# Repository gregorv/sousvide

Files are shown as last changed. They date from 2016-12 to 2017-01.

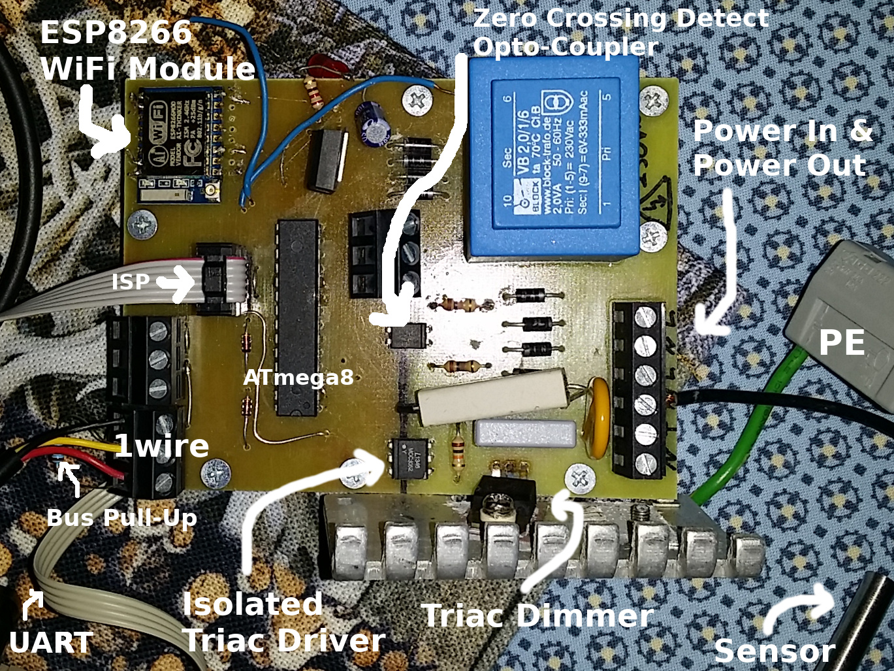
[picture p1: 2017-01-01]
sousvide_ugly_af.jpg

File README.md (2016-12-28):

# sousvide
An ATmega8 based Sous-Vide Temperature Controller

Sous-Vide is a cooking method for a very gentle preparation of meat and vegetables. The general idea is sealing the
food in a vacuum bed and then cooking it in a water bath with a maximum temperature of about 60°C to 70°C for an extended time.
Important cooking reactions (including sterilization) start at around 50°C, but unwanted processes (e.g. meat getting stringy)
increase above 70°C. Because of the lower temperatures the cooking time is elonged, but you get a very even and reproducible
result from the process.

## Overview
### Hardware
On the hardware side (schematics and layout KiCAD format) an ATmega8 regulates the temperature of the water bath with a TRIAC
controlled immersion heater. It is advised to use an acquarium water pump to better spread the heat in the bath. A DS18x2x type
Dallas 1Wire sensor is used for temperature monitoring. The UART can be used to communicate with a ESP8266 type WiFi module, but
is used in the prototype for serial communication and control.

### Firmware
A straight-forward, modularized fixed-point PID controller.

Uses the UART library from Peter Fleury, the 1wire library by Peter Dannegger and the libfixmath by Ben Brewer.

### PC Control Software
Qt5, QCustomPlot, nice.

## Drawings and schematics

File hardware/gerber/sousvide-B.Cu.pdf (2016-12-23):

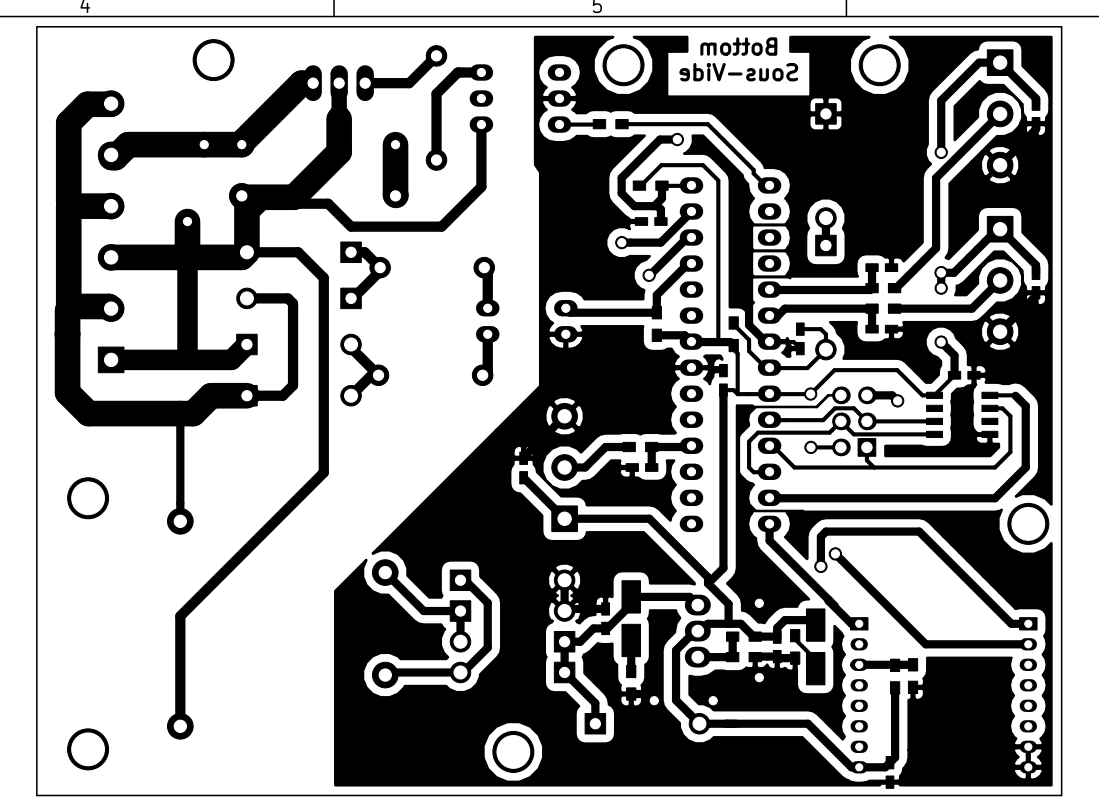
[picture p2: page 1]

Gregor Vollmer
File: sousvide.kicad_pcb Sheet: dynamic-noise.net

Id: 1/1 Title: Sous-Vide Temperature Controler

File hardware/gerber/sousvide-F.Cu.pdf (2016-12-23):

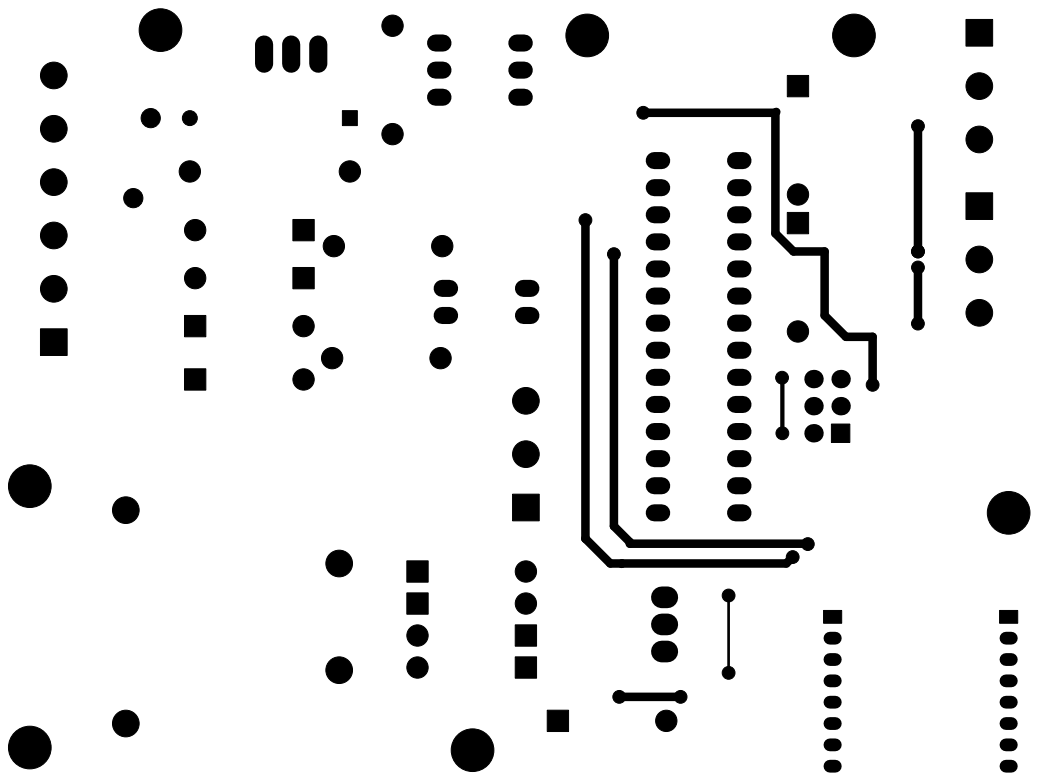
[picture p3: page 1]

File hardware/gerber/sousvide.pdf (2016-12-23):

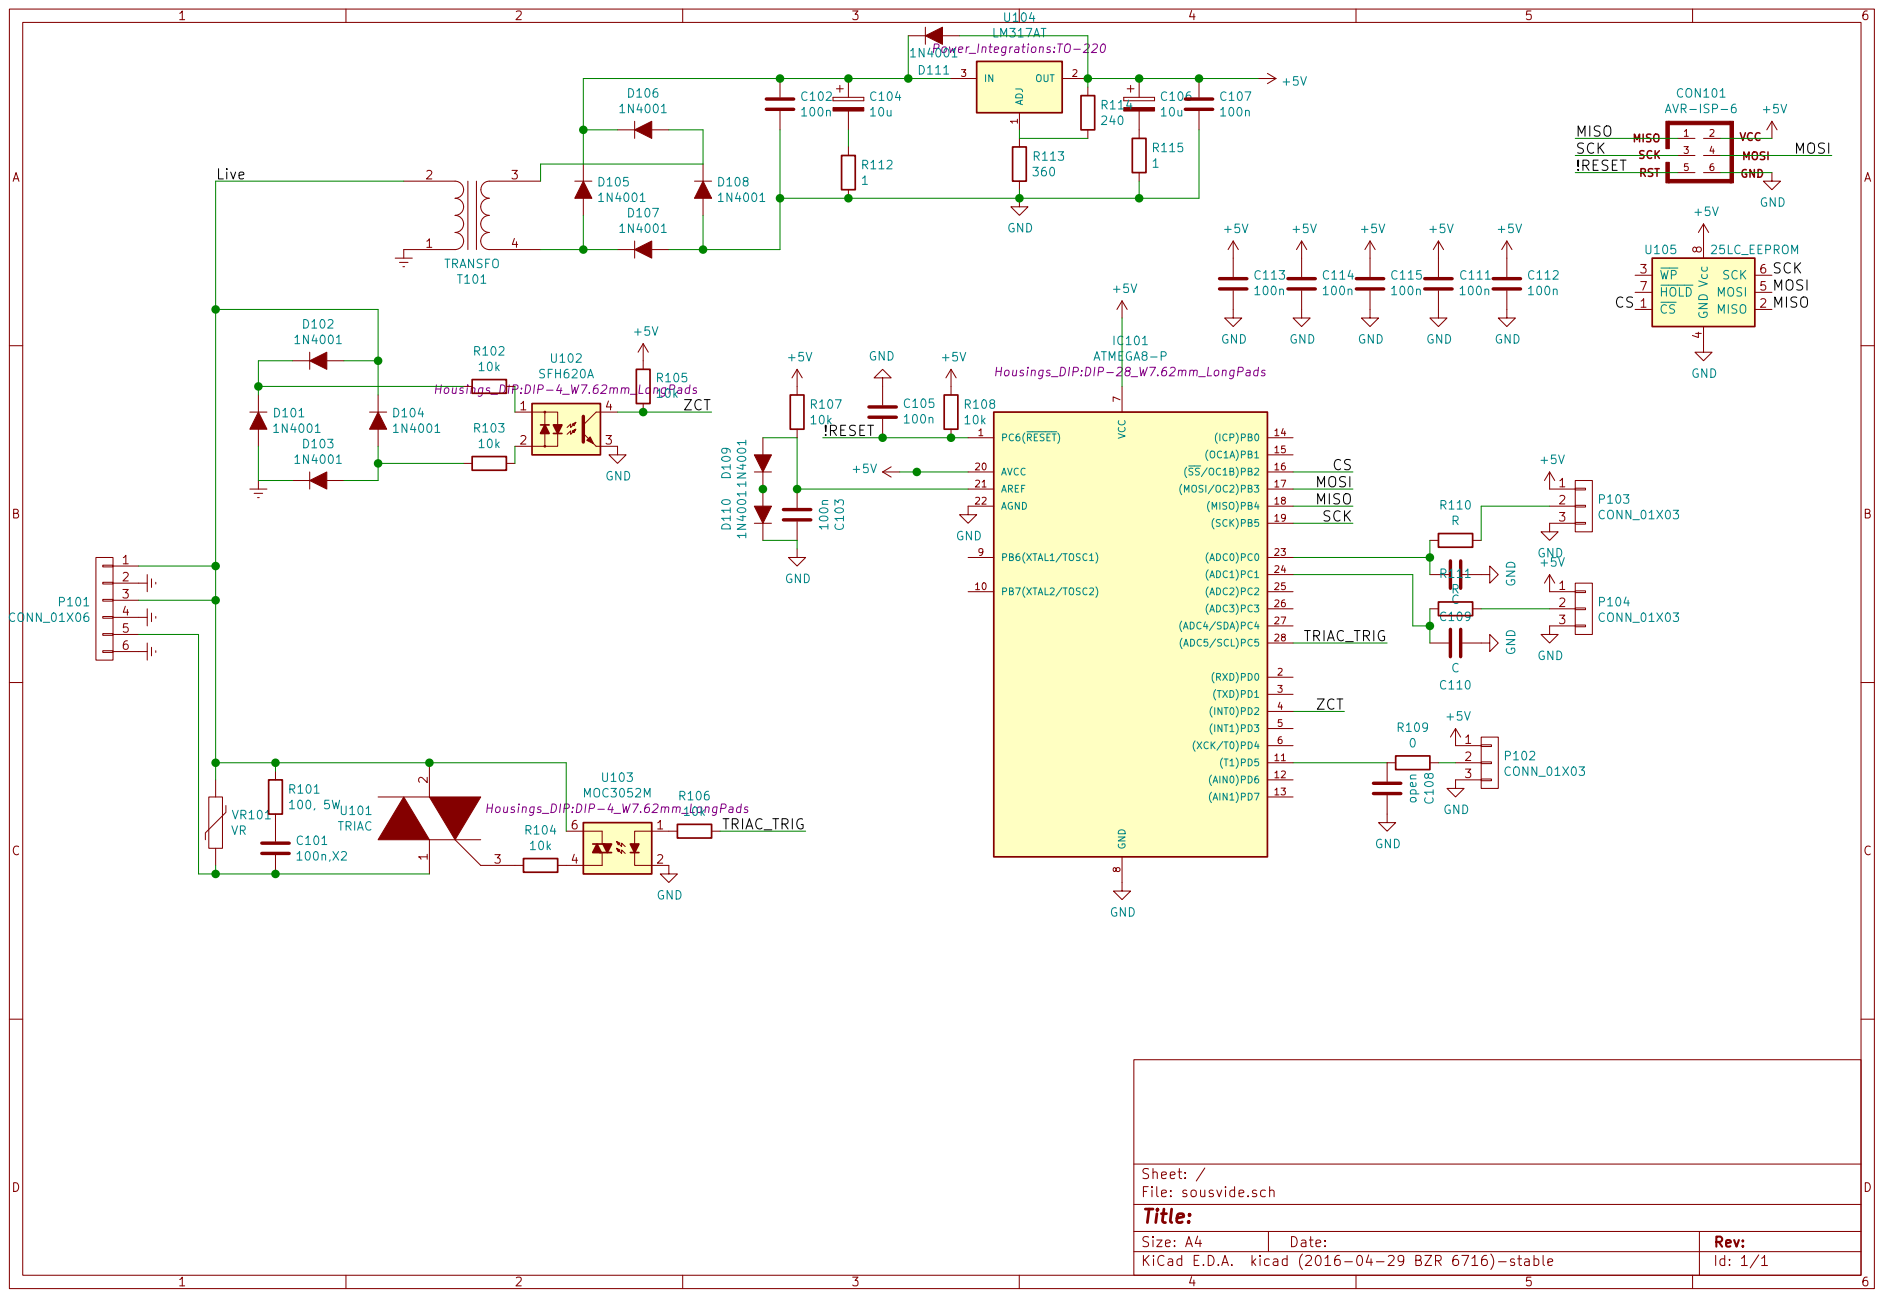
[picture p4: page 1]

4 MOSI 5 SCK 6 HOLD 7 Vcc U105 8

Id: 1/1 Title: File: sousvide.sch Sheet: / 1 2

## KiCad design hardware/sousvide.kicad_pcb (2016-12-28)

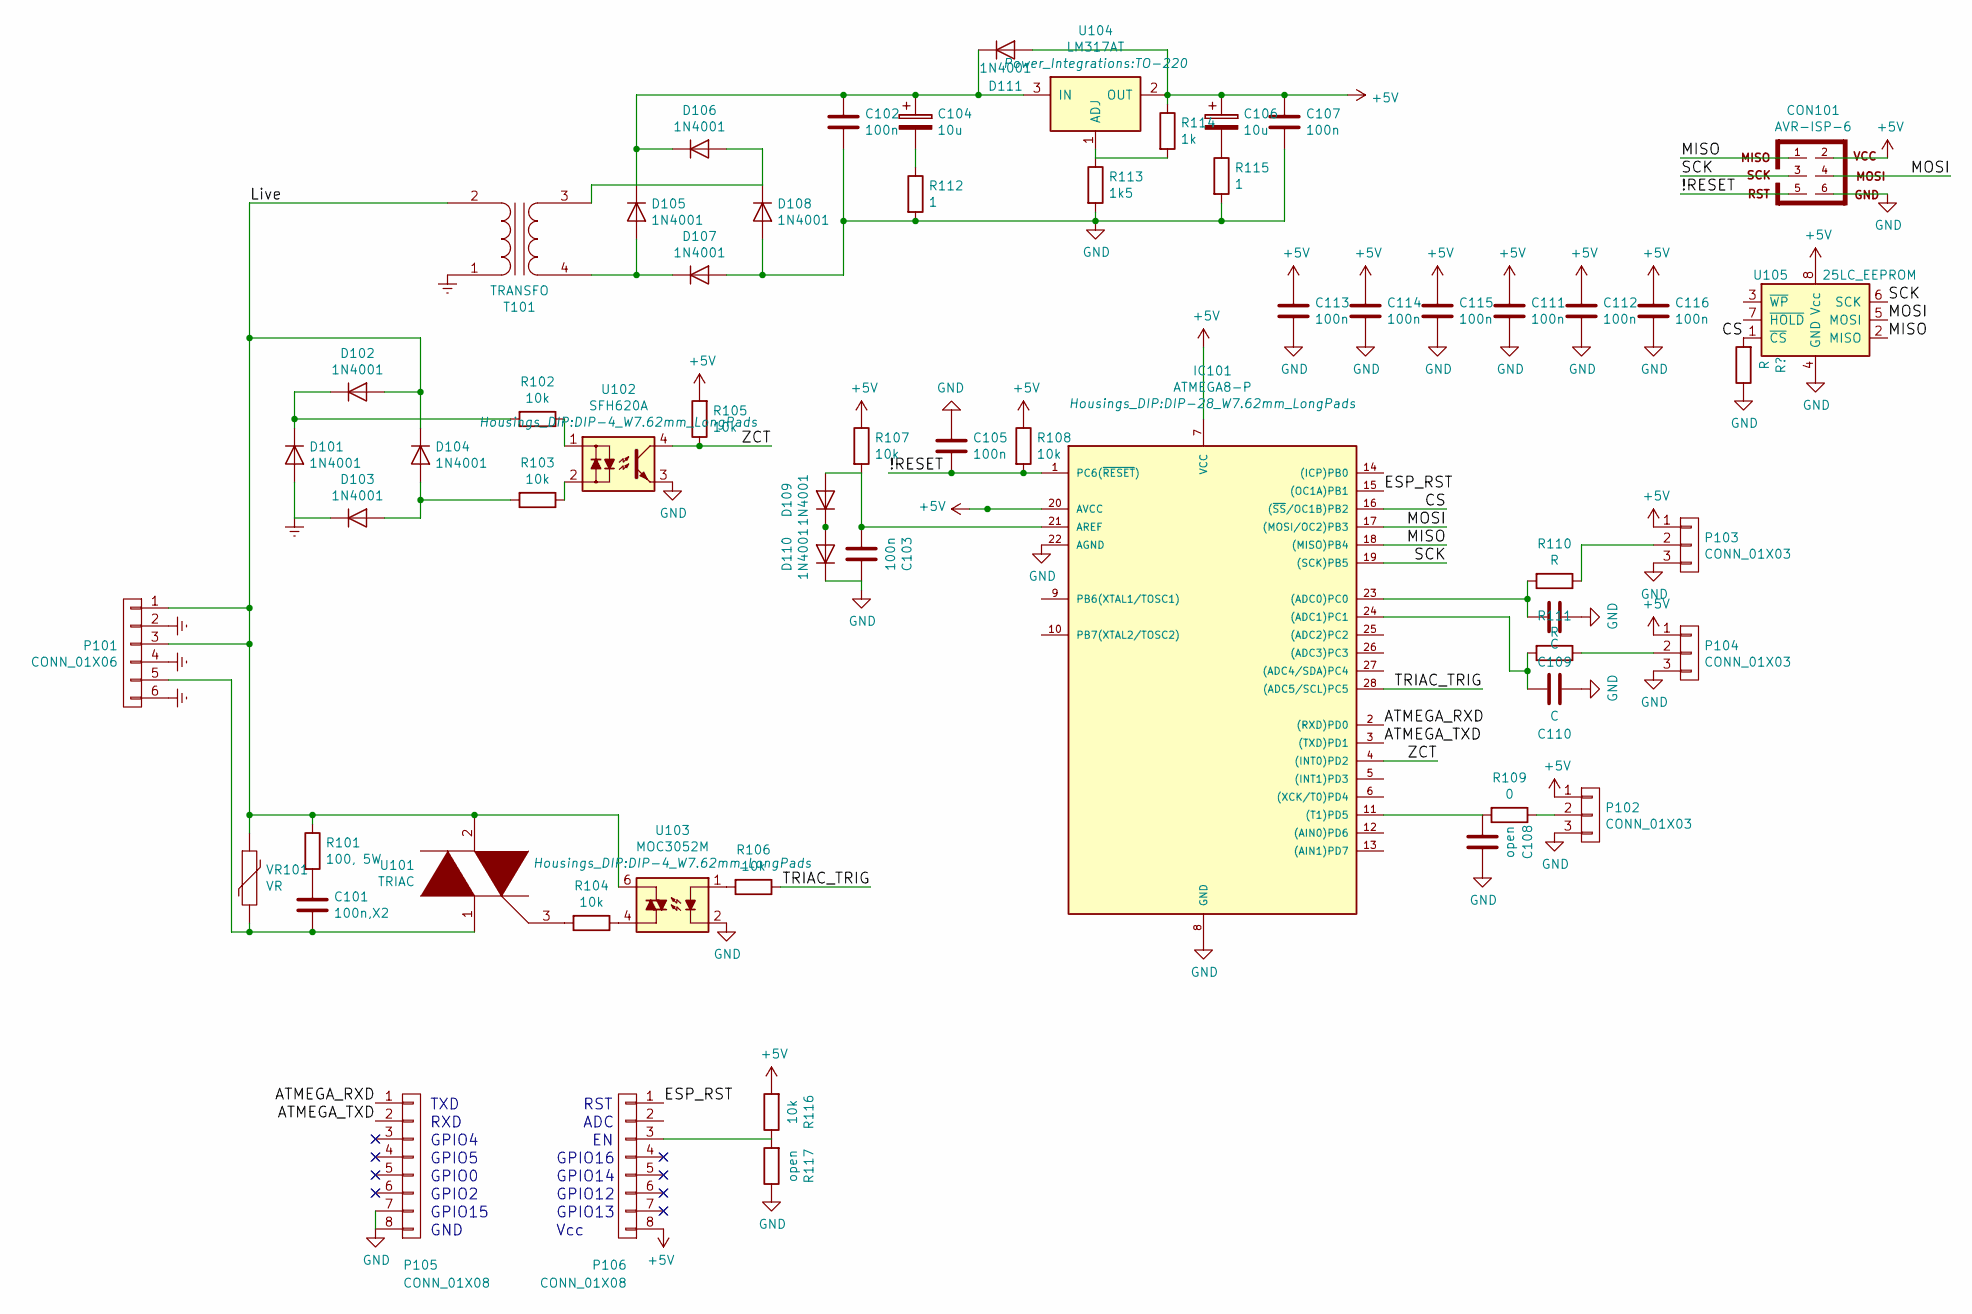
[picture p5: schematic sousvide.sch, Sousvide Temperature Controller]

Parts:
C101: 100n,X2; C_Rect_L18_W6_P15
C102, C103, C105, C107, C111, C112, C113, C114, C115, C116: 100n; C_0603_HandSoldering
C104, C106: 10u; TantalC_SizeB_EIA-3528_HandSoldering
C108: open; C_0603_HandSoldering
C109, C110: C; C_0603_HandSoldering
CON101: AVR-ISP-6; Pin_Header_Straight_2x03
D101, D102, D103, D104, D105, D106, D107, D108, D109, D110, D111: 1N4001; Diode_DO-41_SOD81_Horizontal_RM10
IC101: ATMEGA8-P; DIP-28_W7.62mm_LongPads
P101: CONN_01X06; TerminalBlock_Pheonix_MKDS1.5-6pol
P102, P103, P104: CONN_01X03; TerminalBlock_Pheonix_MKDS1.5-3pol
P105, P106: CONN_01X08; Connectors_JST_B8B-PH-K
R101: 100, 5W; Resistor_Horizontal_RM15mm
R102, R103, R104: 10k; Resistor_Horizontal_RM10mm
R105, R106, R107, R108, R116: 10k; R_0603_HandSoldering
R109: 0; R_0603_HandSoldering
R110, R111: R; R_0603_HandSoldering
R112, R115: 1; R_0603_HandSoldering
R113: 1k5; R_0603_HandSoldering
R114: 1k; R_0603_HandSoldering
R117: open; R_0603_HandSoldering
T101: TRANSFO; BLOCK_VB2,0_1_XX
U101: TRIAC; TO-220_Neutral123_Vertical_LargePads
U102: SFH620A; DIP-4_W7.62mm_LongPads
U103: MOC3052M; DIP-4_W7.62mm_LongPads
U104: LM317AT; TO-220
U105: 25LC_EEPROM; SOIC-8_3.9x4.9mm_Pitch1.27mm
VR101: VR; RV_Disc_D12_W4.2_P7.5

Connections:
+5V: C106.1, C107.1, C111.2, C112.2, C113.2, C114.2, C115.2, C116.2, CON101.2, D111.2 (A), IC101.7 (VCC), IC101.20 (AVCC), P102.1, P103.1, P104.1, P106.8, R105.2, R107.1, R108.1, R114.1, R116.2, U104.2 (OUT), U105.8 (Vcc)
/!RESET: C105.1, CON101.5, IC101.1 (PC6(~RESET~)), R108.2
/ATMEGA_RXD: IC101.2 ((RXD)PD0), P105.1
/ATMEGA_TXD: IC101.3 ((TXD)PD1), P105.2
/CS: IC101.16 ((~SS~/OC1B)PB2), U105.1 (~CS)
/ESP_RST: IC101.15 ((OC1A)PB1), P106.1
/Live: D102.2 (A), D104.1 (K), P101.1, P101.3, R101.1, T101.2 (AB), U101.2, U103.6, VR101.1
/MISO: CON101.1, IC101.18 ((MISO)PB4), U105.2 (MISO)
/MOSI: CON101.4, IC101.17 ((MOSI/OC2)PB3), U105.5 (MOSI)
/SCK: CON101.3, IC101.19 ((SCK)PB5), U105.6 (SCK)
/TRIAC_TRIG: IC101.28 ((ADC5/SCL)PC5), R106.1
/ZCT: IC101.4 ((INT0)PD2), R105.1, U102.4
Earth: D101.2 (A), D103.1 (K), P101.2, P101.4, P101.6, T101.1 (AA)
GND: C102.2, C103.1, C105.2, C107.2, C108.1, C109.2, C110.2, C111.1, C112.1, C113.1, C114.1, C115.1, C116.1, CON101.6, D107.2 (A), D108.2 (A), D110.1 (K), IC101.8 (GND), IC101.22 (AGND), P102.3, P103.3, P104.3, P105.7, P105.8, R112.2, R113.2, R115.2, R117.1, U102.3, U103.2, U105.4 (GND)
unnamed: C101.1, R101.2
unnamed: C101.2, P101.5, U101.1, VR101.2
unnamed: C102.1, C104.1, D105.1 (K), D106.1 (K), D111.1 (K), U104.3 (IN)
unnamed: C103.2, D109.2 (A), IC101.21 (AREF), R107.2
unnamed: C104.2, R112.1
unnamed: C106.2, R115.1
unnamed: C108.2, IC101.11 ((T1)PD5), R109.2
unnamed: C109.1, IC101.23 ((ADC0)PC0), R110.2
unnamed: C110.1, IC101.24 ((ADC1)PC1), R111.2
unnamed: D101.1 (K), D102.1 (K), R102.2
unnamed: D103.2 (A), D104.2 (A), R103.2
unnamed: D105.2 (A), D107.1 (K), T101.4 (SB)
unnamed: D106.2 (A), D108.1 (K), T101.3 (SA)
unnamed: D109.1 (K), D110.2 (A)
unnamed: P102.2, R109.1
unnamed: P103.2, R110.1
unnamed: P104.2, R111.1
unnamed: P106.3, R116.1, R117.2
unnamed: R102.1, U102.1
unnamed: R103.1, U102.2
unnamed: R104.1, U103.4
unnamed: R104.2, U101.3
unnamed: R106.2, U103.1
unnamed: R113.1, R114.2, U104.1 (ADJ)

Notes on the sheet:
RST
ADC
GPIO16
GPIO14
GPIO12
GPIO13
Vcc
TXD
RXD
GPIO4
GPIO5
GPIO0
GPIO2
GPIO15
GND

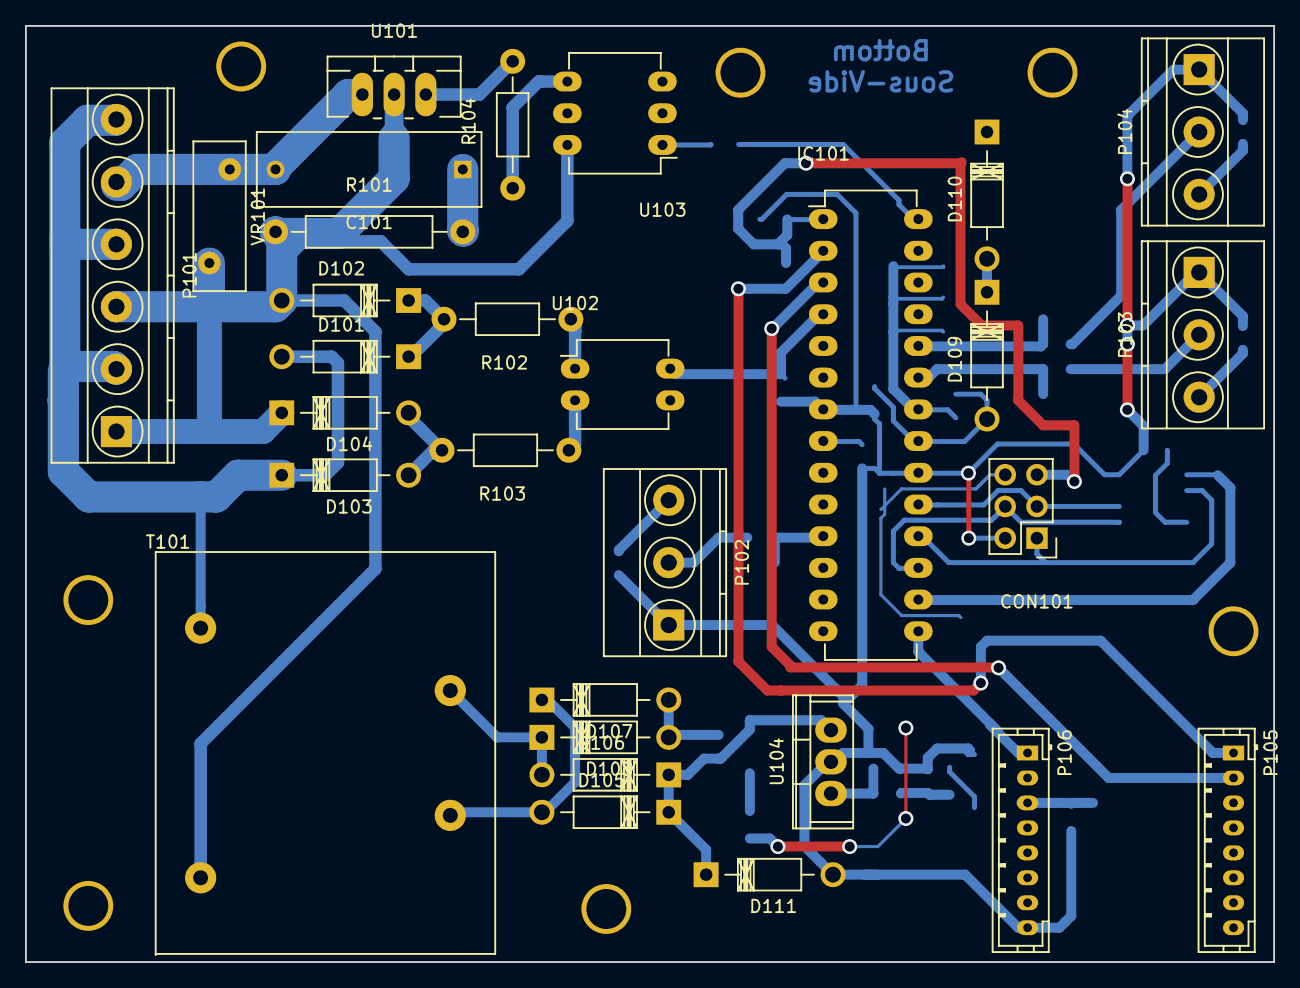
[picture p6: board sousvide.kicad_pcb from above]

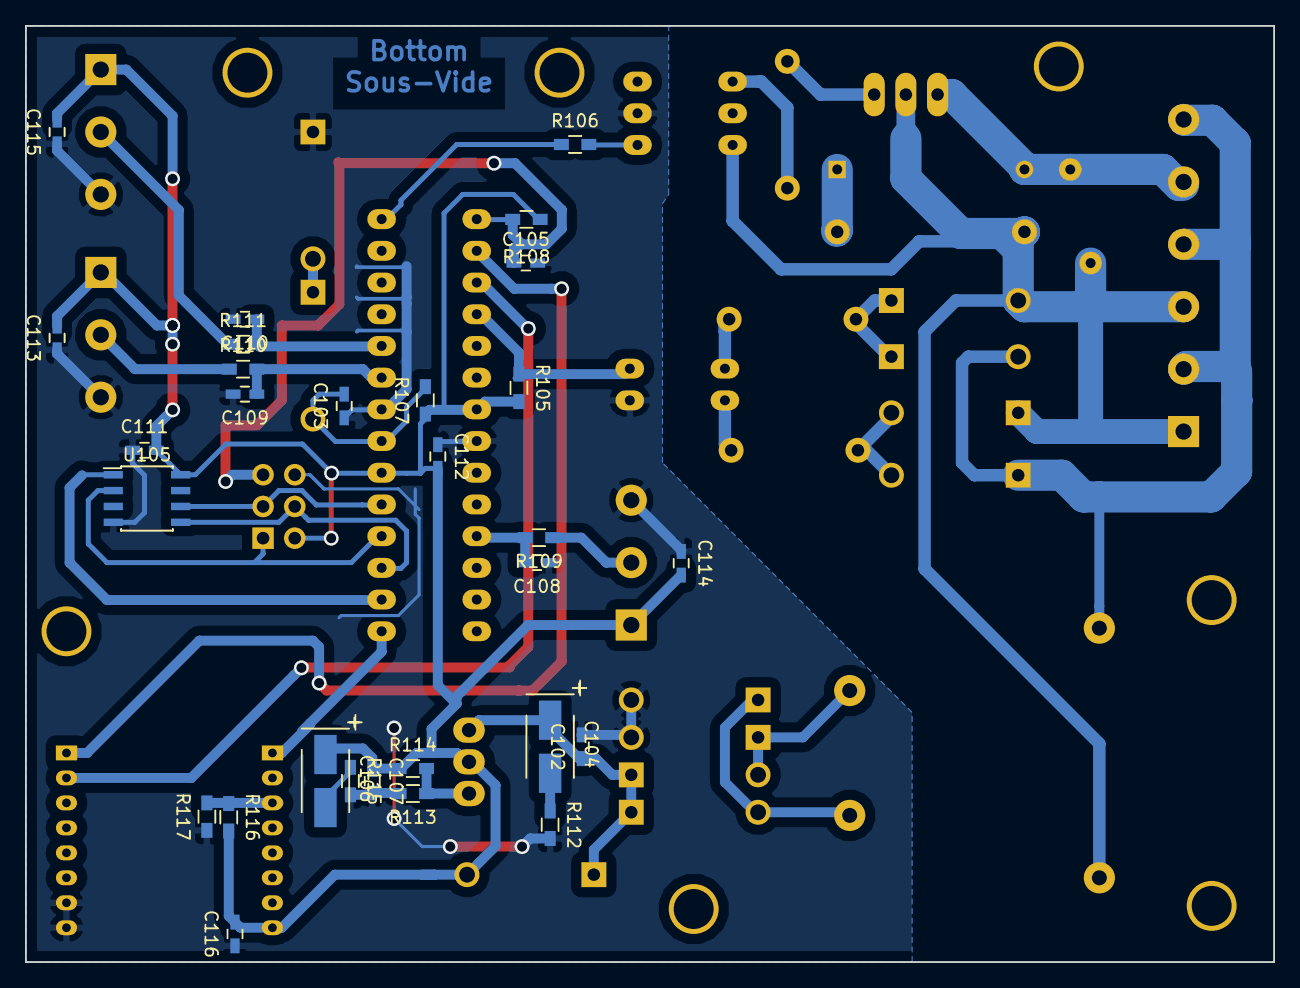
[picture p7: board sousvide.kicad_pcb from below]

Board: 2 copper layers, 100.0 x 75.0 mm, 66 parts (29 on the bottom side), 38 nets.

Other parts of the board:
DR?: drill_3-2
DR?#2, DR?#3, DR?#4, DR?#5, DR?#6, DR?#7: drill_3-2

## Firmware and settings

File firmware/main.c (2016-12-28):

/*  Sousvide-Temperature Controller Firmware
    Copyright (C) 2016 Gregor Vollmer <git@dynamic-noise.net>

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
    You should have received a copy of the GNU General Public License
    along with this program.  If not, see <http://www.gnu.org/licenses/>.
*/
#include "main.h"

fix16_t g_current_temperature;


int tempsens_start_measure(void){
	if( W1_IN & 1<< W1_PIN ){
		w1_command( CONVERT_T, NULL );
		W1_OUT |= 1<< W1_PIN;
		W1_DDR |= 1<< W1_PIN; // parasite power on
	}else{
		uart_puts_P("Short Circuit!\r\n");
		return 0;
	}
	return 1;
}


fix16_t tempsens_get_temperature()
{
	unsigned char id[8], diff;
	for(diff = SEARCH_FIRST; diff != LAST_DEVICE;) {
		diff = w1_rom_search(diff, id);

		if(diff == PRESENCE_ERR) {
			uart_puts_P("\aNo Sensor found\r\n");
			break;
		}
		if(diff == DATA_ERR) {
			uart_puts_P("\aBus Error\r\n");
			break;
		}
		if(id[0] == 0x28 || id[0] == 0x10){	// temperature sensor
			w1_byte_wr(READ);			// read command
			unsigned int temp = w1_byte_rd();	// low byte
			temp |= (uint)w1_byte_rd() << 8;	// high byte
			if( id[0] == 0x10 )			// 9 -> 12 bit
				temp <<= 3;
			fix16_t fixtemp = fix16_from_int(temp) >> 4; // 0.5°C / 8 -> 1/16°C
			return fixtemp;
		}
	}
	uart_puts("\aNo Temperature Sensor\r\n");
	return fix16_min;
}


int main(void)
{
	init_timer();
	uart_init(UART_BAUD_SELECT(F_CPU, BAUD));
	controller_init();
	com_init();
	set_sleep_mode(SLEEP_MODE_IDLE);
	sei();
	uint8_t first = 3;
	for(;;) {
		if(second == 1) {
			tempsens_start_measure();
		} else if(second == 2) {
			g_current_temperature = tempsens_get_temperature();
			if(g_current_temperature == fix16_min) {
				// EMERGENCY SHUTDOWN!!
				controller_disable_dimmer();
			} else {
				if(first) {
					controller_reset(g_current_temperature);
					--first;
				} else {
					controller_step_input_temperature(g_current_temperature);				}
			}
			second = 0;
		}
		com_handle();
		sleep_enable();
		sei();
		sleep_cpu();
		sleep_disable();
	}
	return 0;
}

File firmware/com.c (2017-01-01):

/*  Sousvide-Temperature Controller Firmware
    Copyright (C) 2016 Gregor Vollmer <git@dynamic-noise.net>

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
    You should have received a copy of the GNU General Public License
    along with this program.  If not, see <http://www.gnu.org/licenses/>.
*/
#include "com.h"
#include "uart.h"
#include "controller.h"
#include "version.h"
#define BUF_MAX_LEN 36
#define MAX_ARGS 3
static int g_buf_cur_len;
static char g_buf[BUF_MAX_LEN];
extern fix16_t g_current_temperature;


void com_init()
{
	g_buf_cur_len = 0;
}

static unsigned char hex_to_uchar(const char* twochar)
{
	return (((unsigned char)twochar[0]-'0') << 4)
		+ ((unsigned char)twochar[1]-'0');
}
static fix16_t hex_to_fix16(const char* twochar)
{
	fix16_t f;
	unsigned char* p = (unsigned char*)&f;
	p[3] = hex_to_uchar(twochar);
	p[2] = hex_to_uchar(twochar + 2);
	p[1] = hex_to_uchar(twochar + 4);
	p[0] = hex_to_uchar(twochar + 6);
	return f;
}

static void put_uchar(unsigned char val)
{
	uart_putc(((val&0xf0)>>4) + '0');
	uart_putc((val&0x0f) + '0');
}

static void put_fix16(fix16_t val)
{
	unsigned char* p = (unsigned char*)&val;
	put_uchar(p[3]);
	put_uchar(p[2]);
	put_uchar(p[1]);
	put_uchar(p[0]);
}

static void put_short(short val)
{
	unsigned char* p = (unsigned char*)&val;
	put_uchar(p[1]);
	put_uchar(p[0]);
}

static void com_fail_response(command_t cmd, error_code_t err)
{
	uart_puts_P("FAIL");
	put_uchar(cmd);
	// Error Code 15
	put_uchar(err);
	uart_puts_p(""); // TODO: Implement user friendly message
	uart_puts_P("\r\n");
}

static void com_response_v(command_t cmd, const fix16_t* val, uint8_t n)
{
	uart_puts_P("OKAY");
	put_uchar(cmd);
	for(uint8_t i = 0; i < n; ++i) {
		put_fix16(val[i]);
	}
	uart_puts_P("\r\n");
}

static void com_response_4(command_t cmd, fix16_t a, fix16_t b, fix16_t c, fix16_t d)
{
	uart_puts_P("OKAY");
	put_uchar(cmd);
	put_fix16(a);
	put_fix16(b);
	put_fix16(c);
	put_fix16(d);
	uart_puts_P("\r\n");
}

static void com_response_version(void)
{
	uart_puts_P("OKAY");
	put_uchar(COMMAND_VERSION);
	put_fix16(VERSION_ID);
	put_short(VERSION_MAJOR);
	put_short(VERSION_MINOR);
	uart_puts_P("\r\n");
}

static void com_handle_command(char* cmd, uint8_t len)
{
	if(len < 2) {
		com_fail_response(COMMAND_NO_CMD, ERROR_NO_CMD);
		return;
	}
	command_t command = hex_to_uchar(cmd);
	if((len-2)%8 != 0) {
		com_fail_response(command, ERROR_ARG_SYNTAX);
		return;
	}
	uint8_t nargs = (len-2)>>3;
	if(nargs > MAX_ARGS) {
		com_fail_response(command, ERROR_TOO_MANY_ARGS);
		return;
	}
	fix16_t args[MAX_ARGS];
	for(uint8_t i=0; i<nargs; ++i) {
		args[i] = hex_to_fix16(cmd+2+(i<<3));
	}
	controller_state_t cstate = controller_get_state();
	if(command == COMMAND_GET_P) {
		com_response_v(command, &cstate.p, 1);
	} else if(command == COMMAND_GET_I) {
		com_response_v(command, &cstate.i, 1);
	} else if(command == COMMAND_GET_D) {
		com_response_v(command, &cstate.d, 1);
	} else if(command == COMMAND_GET_TS) {
		com_response_v(command, &cstate.setpoint, 1);
	} else if(command == COMMAND_GET_TI) {
		com_response_v(command, &g_current_temperature, 1);
	} else if(command == COMMAND_VERSION) {
		com_response_version();
	} else if(command == COMMAND_SET_P) {
		if(nargs != 1) {
			com_fail_response(command, ERROR_ARG_MISMATCH);
		} else {
			controller_set_constant_p(args[0]);
			com_response_v(command, args, 1);
		}
	} else if(command == COMMAND_SET_I) {
		if(nargs != 1) {
			com_fail_response(command, ERROR_ARG_MISMATCH);
		} else {
			controller_set_constant_i(args[0]);
			com_response_v(command, 0, 0);
		}
	} else if(command == COMMAND_SET_D) {
		if(nargs != 1) {
			com_fail_response(command, ERROR_ARG_MISMATCH);
		} else {
			controller_set_constant_d(args[0]);
			com_response_v(command, 0, 0);
		}
	} else if(command == COMMAND_SET_TS) {
		if(nargs != 1) {
			com_fail_response(command, ERROR_ARG_MISMATCH);
		} else {
			controller_set_setpoint_temperature(args[0]);
			com_response_v(command, 0, 0);
		}
	} else if(command == COMMAND_PID_DIAG) {
		com_response_4(command, cstate.integral, cstate.derivative,
		               fix16_from_int(cstate.output),
			       cstate.slow_temp);
	} else if(command == COMMAND_SOFT_RESET) {
		controller_reset(fix16_min);
		com_response_v(command, 0, 0);
	}
}

void com_handle()
{
	for(;;) {
		unsigned int data = uart_getc();
		if(data & UART_NO_DATA) {
			break;
		}
		g_buf[g_buf_cur_len++] = data & 0xFF;
		int cmdlen = 0;
		for(cmdlen = 0; cmdlen < g_buf_cur_len-1; ++cmdlen) {
			if(g_buf[cmdlen] == '\r' && g_buf[cmdlen+1] == '\n') {
				break;
			}
		}
		if(cmdlen < g_buf_cur_len-1) {
			com_handle_command(g_buf, cmdlen);
			int newlen = 0;
			for(int i = cmdlen + 2; i < g_buf_cur_len; ++i) {
				g_buf[i-cmdlen-2] = g_buf[i];
				newlen++;
			}
			g_buf_cur_len = newlen;
		}
		if(g_buf_cur_len == BUF_MAX_LEN) {
			// invalid command received!
			// shift buffer by one char
			for(int i=0; i < g_buf_cur_len-1; ++i) {
				g_buf[i] = g_buf[i+1];
			}
			g_buf_cur_len -= 1;
		}
		/*for(int i=0; i<g_buf_cur_len; ++i) {
			uart_putc(g_buf[i]);
		}
		uart_putc('\b');*/
	}
}

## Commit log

2016-12-23 Added schematics, PCB layout and footprint library
    [sousvide.kicad_pcb, sousvide.sch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]
2016-12-25 Added Peter Fleurys UART library
2016-12-28 Implemented PID controller
2016-12-28 Added serial communication module
    Handles and responds to commands over the UART interface.
2016-12-28 Added Licensing information and authors file
    [sousvide.kicad_pcb, sousvide.sch]
2016-12-28 Main Program: Removed old code and included new modules
    Use control and com module and glue it together with onewire
    temperature readout.
2016-12-28 Changed flash targets
    * Added target flash-fuses
    * Do not perform mandatory chip-erase, but make it configurable
    via the AVRDUDE_FLAGS variable
2016-12-28 Startet user application for controlling the souvide-device
    A small Qt5 based GUI application for setting and receiving the
    controller settings. An "extensive" visualisation (via QQustomPlot)
    is planned but not yet implemented.
2016-12-28 Fixed C warning messages
    Code (except for libfixmath) is now free of many optional GCC warnings.
    The flags pointer-sign and conversion are suppressed because they are
    problematic with Peter Danneggers 1wire code and libfixmath headers.
    The following warning flags are enabled:
    * -Wall
    * -Wpedantic
    * -Wshadow
    * -Wcast-qual
    * -Wstrict-prototypes (implies foo(void))
    * -Wmissing-prototypes (require prototypes for non-static functions)
    * -Wformat
    * -Wswitch-default
    * -Wcast-align
    * -Wbad-function-cast
    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
    [com.c, main.c, main.h]
2016-12-29 Added support for a simple temperature plot
2016-12-31 Implemented temperature plot
2017-01-01 Improved control GUI
    * Reworked the overall style and organisation
    * Added icons
    * Automatic scanning for connected Sousvide-Devices
    * Added cooking timer
2017-01-01 Added very ugly annotated image from revision 1 of hardware prototype
    :)

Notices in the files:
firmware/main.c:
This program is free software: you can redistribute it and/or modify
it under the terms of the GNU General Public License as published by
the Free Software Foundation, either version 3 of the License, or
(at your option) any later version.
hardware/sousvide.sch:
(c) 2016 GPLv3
